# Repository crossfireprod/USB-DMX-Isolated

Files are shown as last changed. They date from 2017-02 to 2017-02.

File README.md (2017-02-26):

Fully Isolated USB DMX Adapter
==================

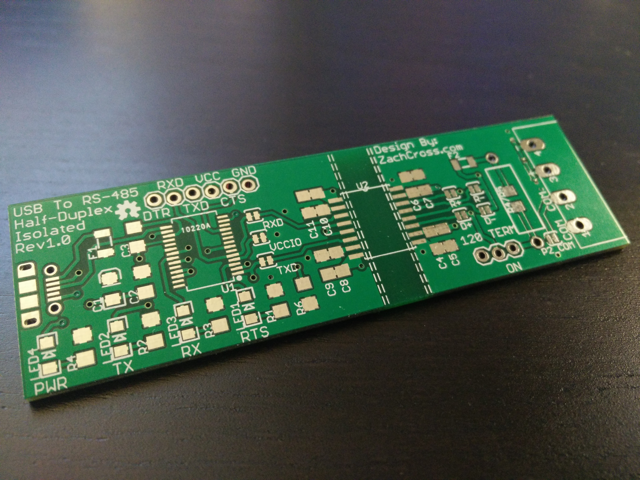
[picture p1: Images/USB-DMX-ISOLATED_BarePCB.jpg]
USB DMX Isolated - Bare PCB
  

This USB DMX adapter is designed to be an functional foray into PCB design and assembly using primarily surface mount components.  The use of an isolating RS-485 transceiver differentiates this USB DMX adapter from others that can be purchased or built at a similar price point.

Bill Of Materials
-------------------

A Bill Of Materials detailing the specific parts used in my most recent production run can be found on [Octopart](https://octopart.com/bom-tool/TxEq1b9y).  Pricing is more or less optimized around single unit quanties.

Repository Contents
-------------------

* **/Hardware** - Eagle Schematic & PCB Layout
* **/Images** - Images of the schematic / PCB design, as well as fully assembled USB DMX adapters.

License
-------------------

All contents of this repository are released under [Creative Commons Share-alike 4.0](http://creativecommons.org/licenses/by-sa/4.0/).

NOTE:  While every effort was made to follow the necessary design rules to maintain proper isolation between the USB and RS-485 interfaces, this design is a hobby project and as such should *not* be relied upon to protect life, limb, your equipment, etc.

Design By: [*ZachCross.com*](https://ZachCross.com)

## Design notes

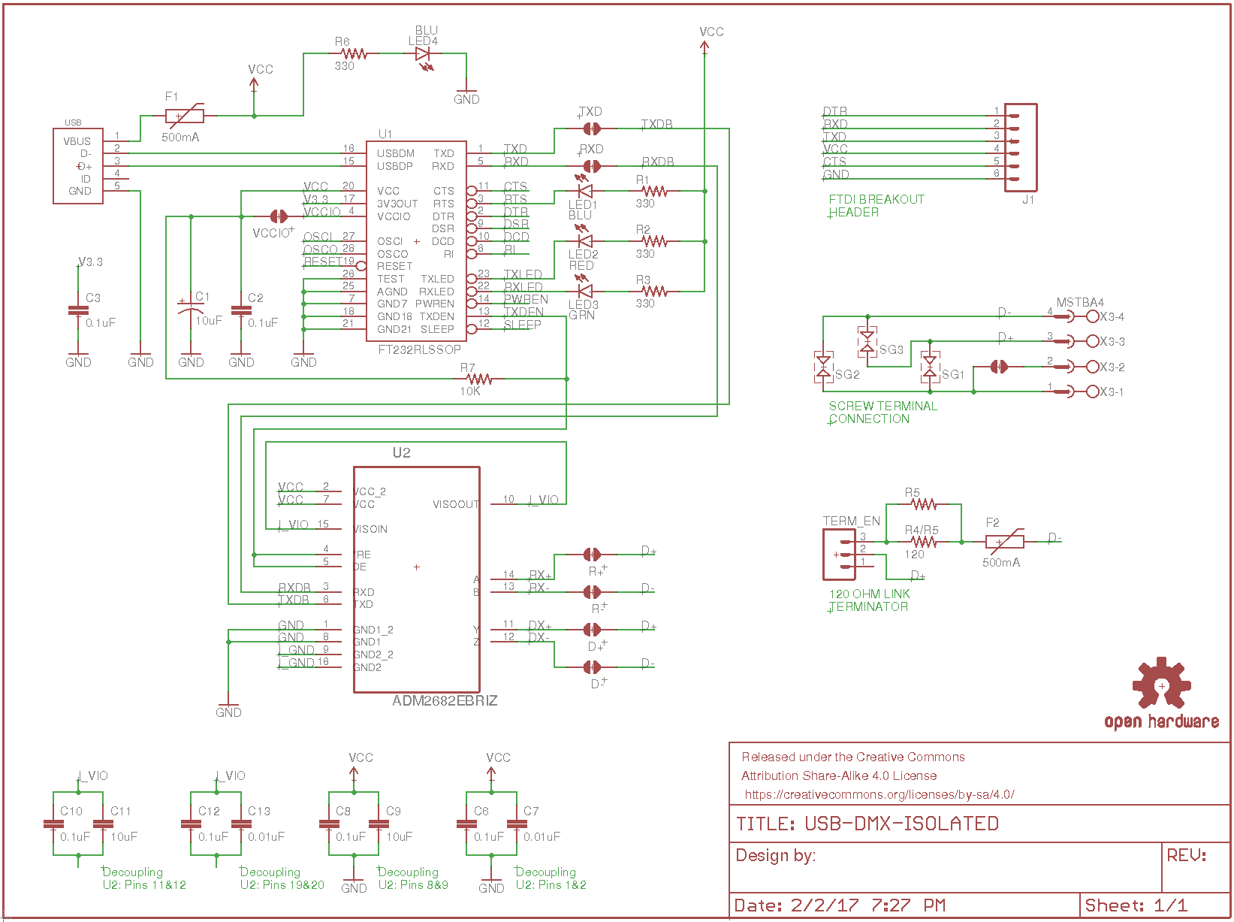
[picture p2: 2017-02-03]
Images/USB-DMX-ISOLATED_Schematic.png

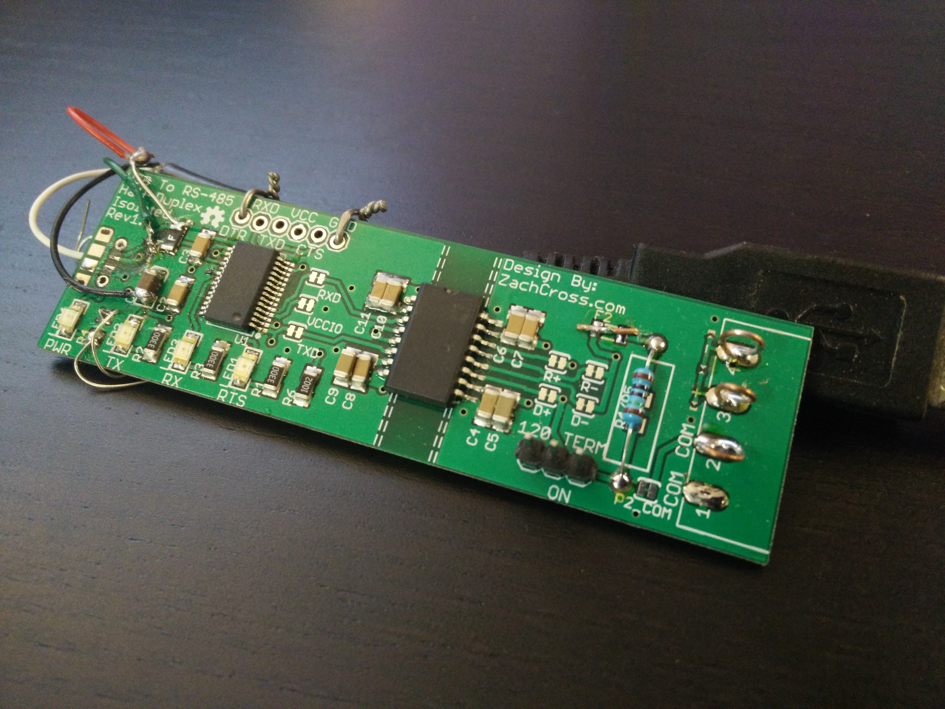
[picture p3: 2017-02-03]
Images/USB-DMX-ISOLATED_FirstPrototype.jpg

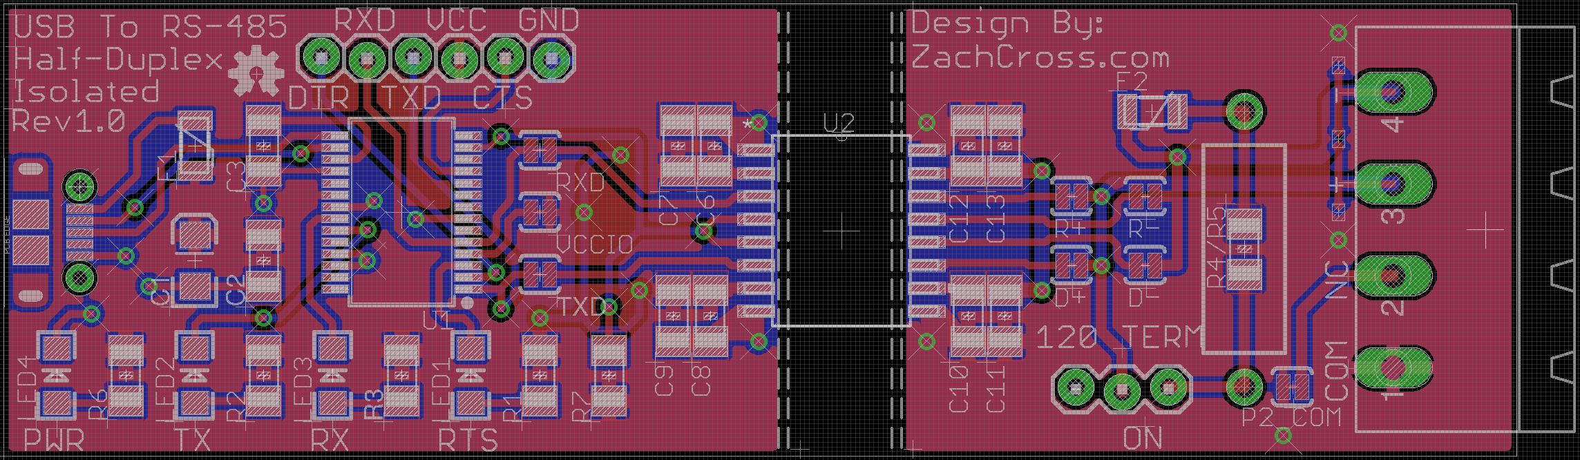
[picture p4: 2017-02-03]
Images/USB-DMX-ISOLATED_PCBLayout.png

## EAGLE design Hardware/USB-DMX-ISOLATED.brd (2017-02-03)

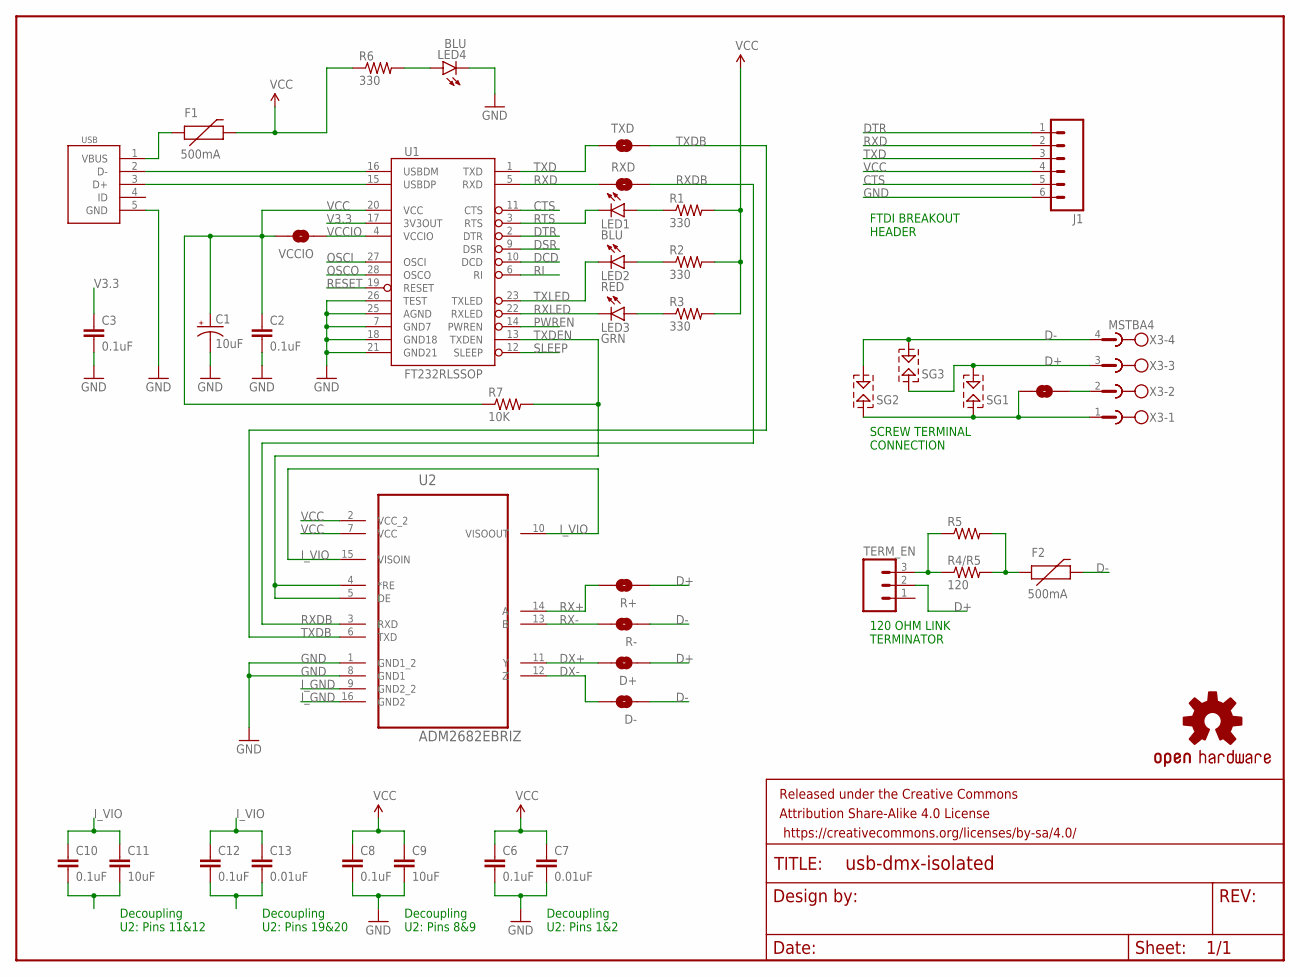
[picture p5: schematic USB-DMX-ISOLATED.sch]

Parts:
C1: 10uF; EIA3216
C2, C3, C6, C8, C10, C12: 0.1uF; 1206
C7, C13: 0.01uF; 1206
C9, C11: 10uF; 1206
D+: SOLDERJUMPERTRACE; SJ_2S-TRACE
D-: SOLDERJUMPERTRACE; SJ_2S-TRACE
F1, F2: 500mA; PTC-1206
FRAME1: FRAME-LETTERNO_PACKAGE; DUMMY
J1: M06LOCK; 1X06_LOCK
LED1, LED4: BLU; LED-1206
LED2: RED; LED-1206
LED3: GRN; LED-1206
LOGO1: OSHW-LOGOS; OSHW-LOGO-S
P2_COM: SOLDERJUMPERTRACE; SJ_2S-TRACE
R1, R2, R3, R6: 330; 1206
R4/R5: 120; 1206
R5: RESISTORPTH-1W; AXIAL-0.6
R7: 10K; 1206
R+: SOLDERJUMPERTRACE; SJ_2S-TRACE
R-: SOLDERJUMPERTRACE; SJ_2S-TRACE
RXD: SOLDERJUMPERTRACE; SJ_2S-TRACE
SG1, SG2, SG3: SPARK-GAP-8
TERM_EN: M03LOCK; 1X03_LOCK
TXD: SOLDERJUMPERTRACE; SJ_2S-TRACE
U1: FT232RLSSOP; SSOP28DB
U2: ADM2682EBRIZ; SOIC127P1032X265-16N
USB: USB-CON-5PIN-105017-0001; USB-MICRO-MOLEX-105017-0001
VCCIO: SOLDERJUMPERTRACE; SJ_2S-TRACE
X3: MSTBA4

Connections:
CTS: J1.5, U1.11 (CTS)
D+: D+.1, R+.1, SG1.1, SG3.2, TERM_EN.2, X3.3
D-: D-.1, F2.2, R-.1, SG2.1, SG3.1, X3.4
DCD: U1.10 (DCD)
DSR: U1.9 (DSR)
DTR: J1.1, U1.2 (DTR)
DX+: D+.2, U2.11 (Y)
DX-: D-.2, U2.12 (Z)
GND: C1.C (-), C2.2, C3.2, C6.2, C7.2, C8.2, C9.2, J1.6, LED4.C, U1.7 (GND7), U1.18 (GND18), U1.21 (GND21), U1.25 (AGND), U1.26 (TEST), U2.1 (GND1_2), U2.8 (GND1), USB.5 (GND)
I_GND: C10.2, C11.2, C12.2, C13.2, P2_COM.1, SG1.2, SG2.2, U2.9 (GND2_2), U2.16 (GND2), X3.1
I_VIO: C10.1, C11.1, C12.1, C13.1, U2.10 (VISOOUT), U2.15 (VISOIN)
unnamed: LED4.A, R6.2
unnamed: P2_COM.2, X3.2
unnamed: R4/R5.1, R5.P$1 (1), TERM_EN.3
unnamed: F2.1, R4/R5.2, R5.P$2 (2)
unnamed: LED3.A, R3.1
unnamed: LED1.A, R1.1
unnamed: LED2.A, R2.1
OSCI: U1.27 (OSCI)
OSCO: U1.28 (OSCO)
PWREN: U1.14 (PWREN)
RESET: U1.19 (RESET)
RI: U1.6 (RI)
RTS: LED1.C, U1.3 (RTS)
RX+: R+.2, U2.14 (A)
RX-: R-.2, U2.13 (B)
RXD: J1.2, RXD.1, U1.5 (RXD)
RXDB: RXD.2, U2.3 (RXD)
RXLED: LED3.C, U1.22 (RXLED)
SLEEP: U1.12 (SLEEP)
TXD: J1.3, TXD.1, U1.1 (TXD)
TXDB: TXD.2, U2.6 (TXD)
TXDEN: R7.2, U1.13 (TXDEN), U2.4 (*RE), U2.5 (DE)
TXLED: LED2.C, U1.23 (TXLED)
USB_D+: U1.15 (USBDP), USB.3 (D+)
USB_D-: U1.16 (USBDM), USB.2 (D-)
V3.3: C3.1, U1.17 (3V3OUT)
VBUS: F1.1, USB.1 (VBUS)
VCC: C1.A (+), C2.1, C6.1, C7.1, C8.1, C9.1, F1.2, J1.4, R1.2, R2.2, R3.2, R6.1, R7.1, U1.20 (VCC), U2.2 (VCC_2), U2.7 (VCC), VCCIO.2
VCCIO: U1.4 (VCCIO), VCCIO.1

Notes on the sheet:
Decoupling U2: Pins 1&2
Decoupling U2: Pins 8&9
Decoupling U2: Pins 11&12
Decoupling U2: Pins 19&20
120 OHM LINK TERMINATOR
SCREW TERMINAL CONNECTION
FTDI BREAKOUT HEADER

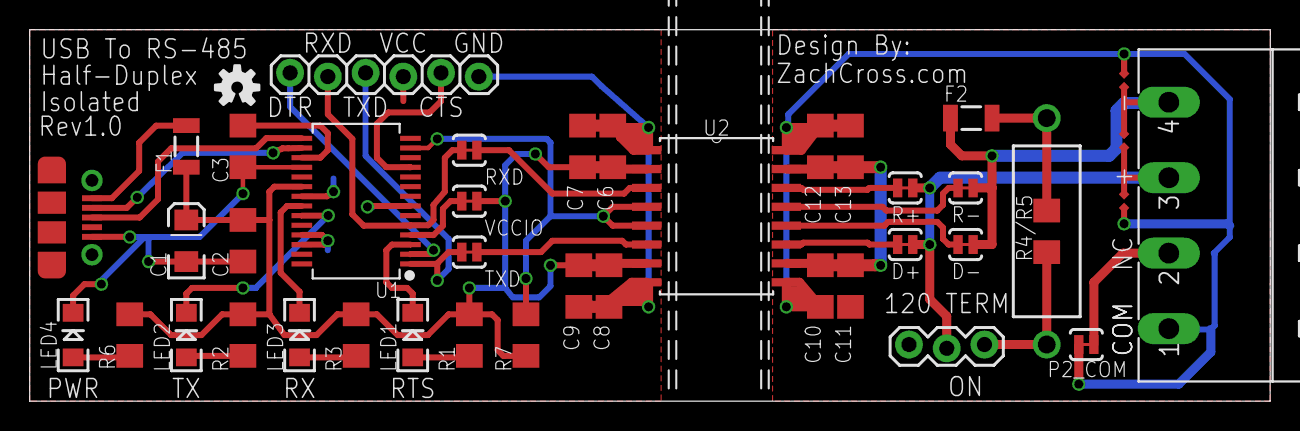
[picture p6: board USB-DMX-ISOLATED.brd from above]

Board: 2 copper layers, 83.5 x 25.0 mm, 43 parts (0 on the bottom side), 32 nets.

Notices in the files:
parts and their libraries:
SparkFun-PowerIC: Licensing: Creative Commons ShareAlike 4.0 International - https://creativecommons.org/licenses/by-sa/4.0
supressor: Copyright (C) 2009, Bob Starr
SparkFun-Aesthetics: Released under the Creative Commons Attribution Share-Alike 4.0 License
